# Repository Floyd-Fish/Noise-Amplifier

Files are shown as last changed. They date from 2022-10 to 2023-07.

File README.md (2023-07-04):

# Noise Amplifier

An ultra-low noise amplifier **(named EmoeNAP)** capable to measure low-noise LDO/OPA's wide band output noise, and many other interesting measurements. Referred to **[AN-159](https://www.analog.com/en/app-notes/an-159.html)**.

The full article about the initial version of Noise Amp can be found here:**[How to build a Noise Amplifier](https://www.emoe.xyz/noise-amplifier-building-instruction/)**. And to step further, to build the current version named **EmoeNAP**，please follow **[Noise Amplifier Step further](https://www.emoe.xyz/noise-amplifier-step-further/)**

Test result show that: with input shorted, the total output noise in 100kHz bandwidth is 1.76mVrms, and **the EmoeNAP's Gain equals to 80dB**, which results in **176nVrms input noise.**

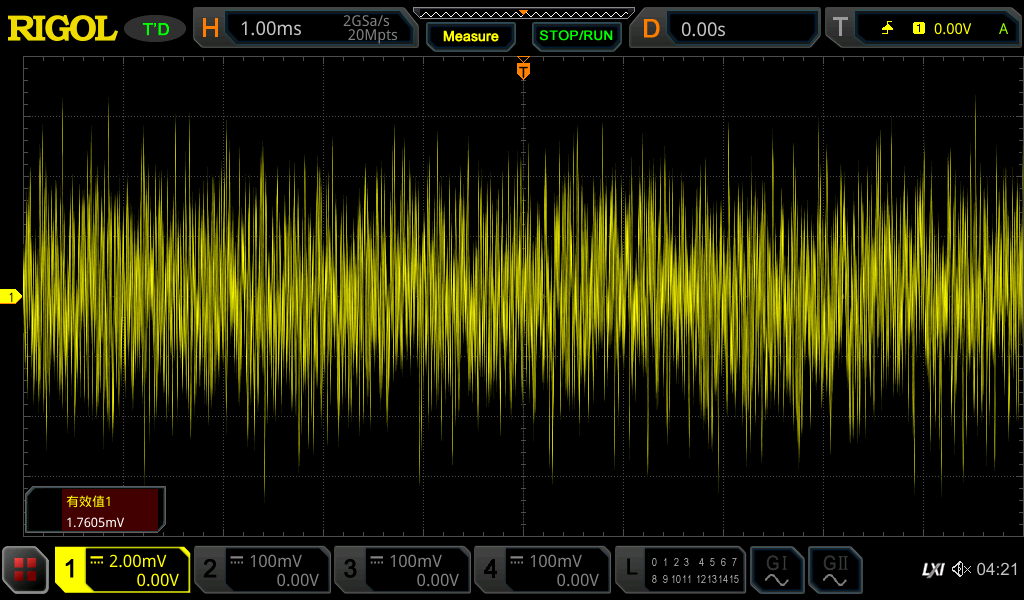
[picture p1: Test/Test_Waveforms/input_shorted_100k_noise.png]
input_shorted_noise


Then connect a 50 ohms SMA Load to input, the total output noise in 100kHz bandwidth is 3.65mVrms, which equals in 365nVrms input noise.

A 50 ohms resistor's Johnson-Nyquist Noise(Themal noise) in 100kHz is 316nVrms(Theoretical), and 316nVrms combine with 176nVrms, resulting 361nVrms total output noise. This test verified the EmoeNAP's extraordinary ability to measure a 50 ohms resistor's Thermal Noise precisely.

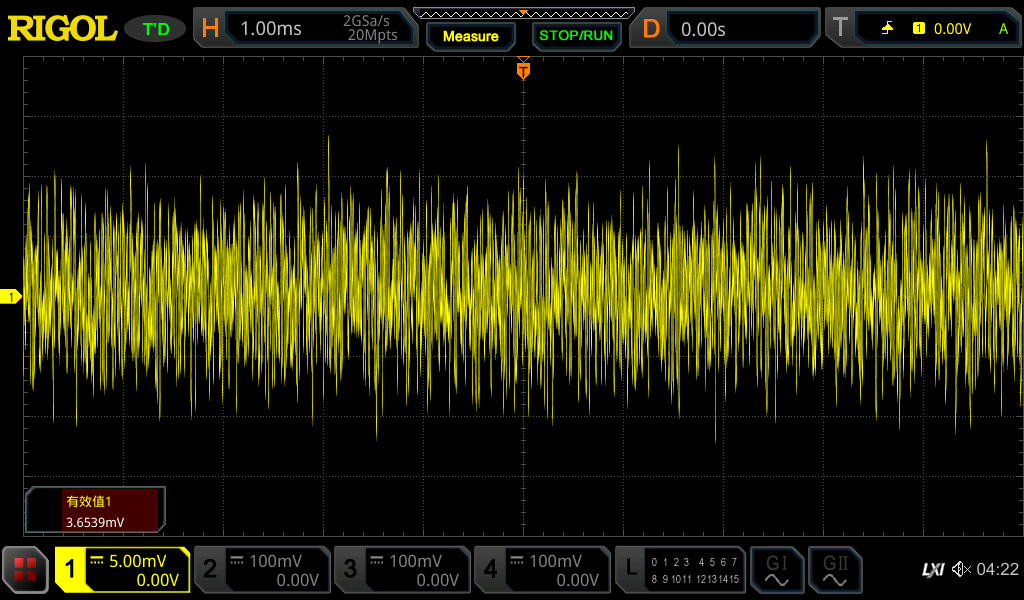
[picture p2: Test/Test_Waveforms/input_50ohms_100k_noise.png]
input_50ohms_noise


# Still In Progress

**V2.3 has been verified but still needs improving.**    
In next version of EmoeNAP, I plan to change its architecture a little to the form below:

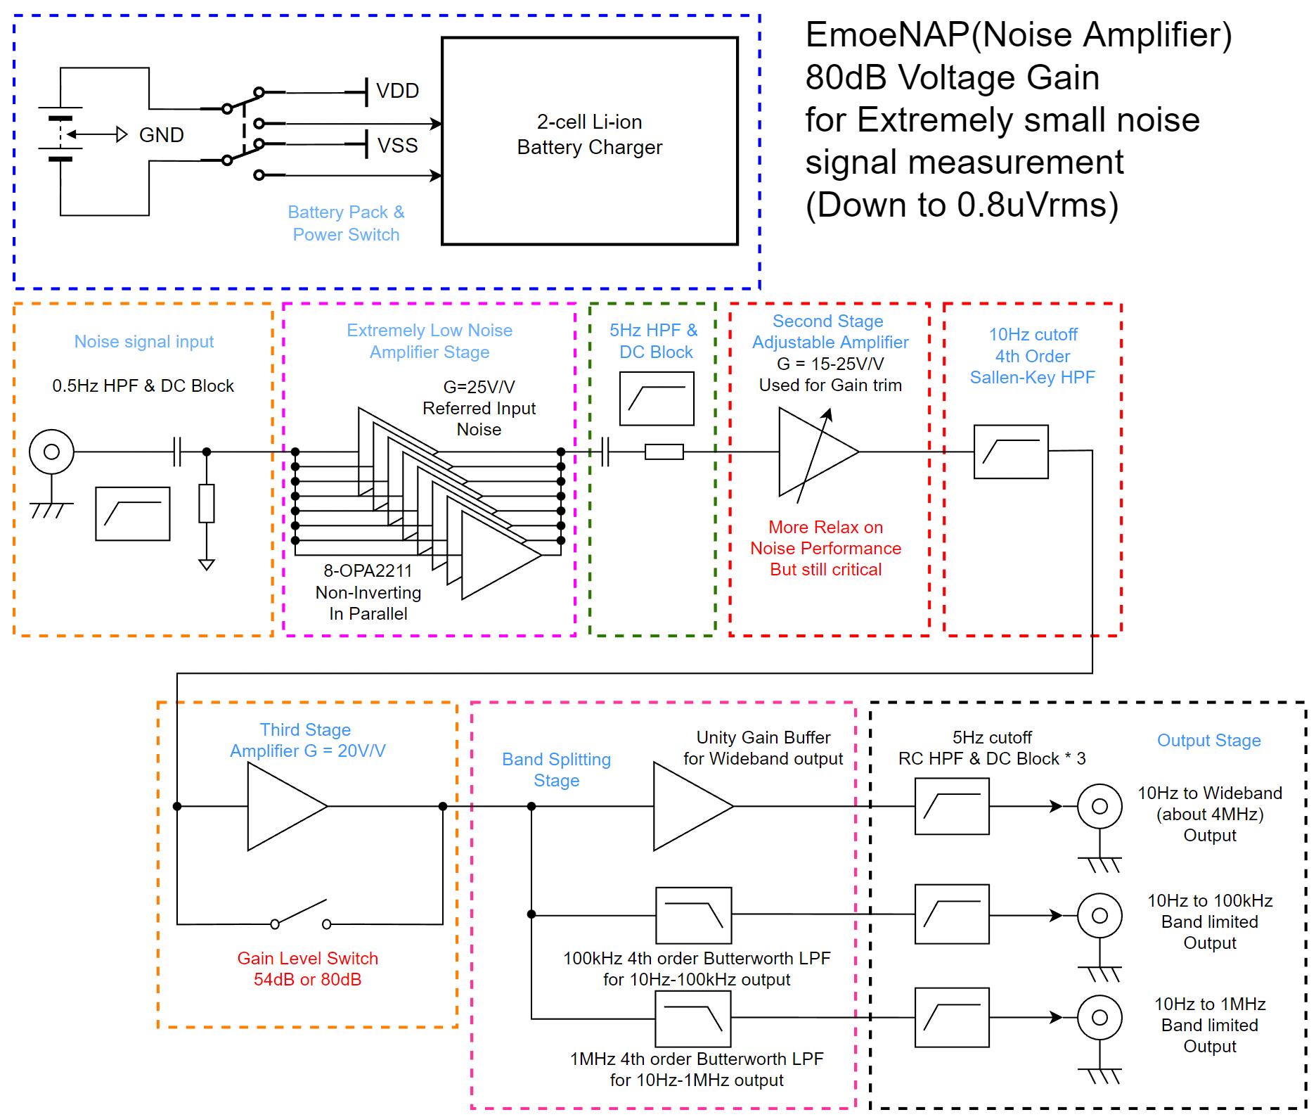
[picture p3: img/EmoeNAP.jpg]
EmoeNAP_Arch


## V2.3 Known Issue

- Poor layout of output low-pass filter, to be re-designed.  
- Input Riso is not needed, because it introduces more thermal noise to input.(Can be seen as source impedance)  
- A resistor should be connected in series at wideband output port, because capacitive load( osilloscope input port, such as) can cause loop instability problem, so a resistor is needed to isolate the opamp output to load capacitor. A common value of 100 ohms is recommended.

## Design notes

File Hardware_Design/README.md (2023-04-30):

# Hardware Specs

- NoiseAMP_BAT
> The battery pack for Noise Amplifier. Two 14500 Type 3.7V Li-ion Battery are used to provide ultralow power rail noise and high output current for NoiseAMP to work.

- NoiseAMP_V2.3(**Aborted**)
> The main PCB of the initial version of NoiseAMP, the current revision named EmoeNAP.

- EmoeNAP
> The current main PCB of NoiseAMP, called EmoeNAP, too.

To build a single cell EmoeNAP，**just use EmoeNAP is enough**.  
To build a 2-cell EmoeNAP, maybe you could have a look at NoiseAMP_BAT.

> Using one cell is more convenient to charge the battery, but will degrade noise performance a little bit.  
> Using two cell would get the best noise performance of EmoeNAP.

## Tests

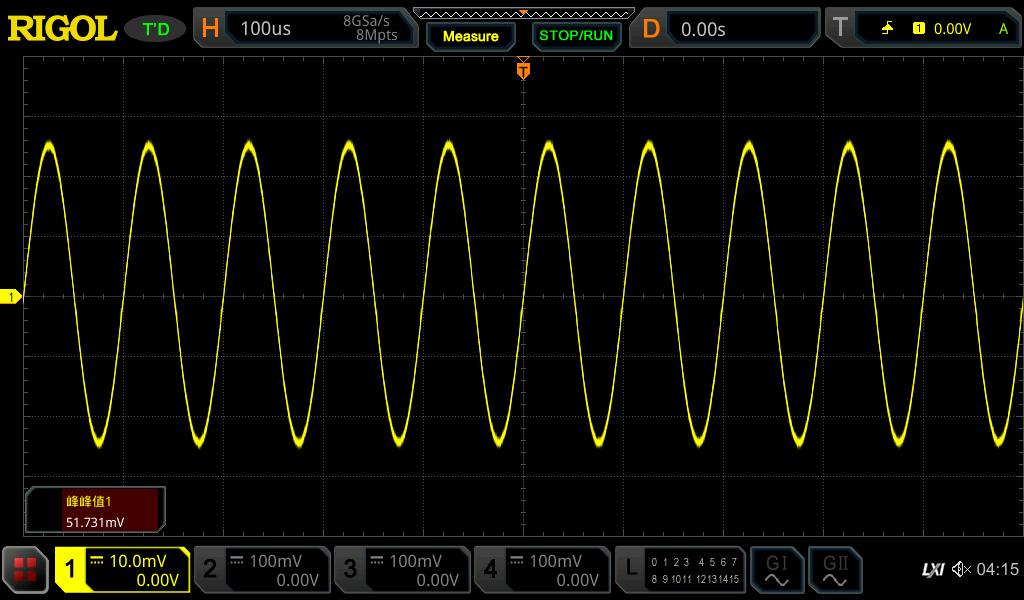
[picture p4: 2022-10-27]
Test/Test_Waveforms/40dB ATT 50mVpp Calibration.png

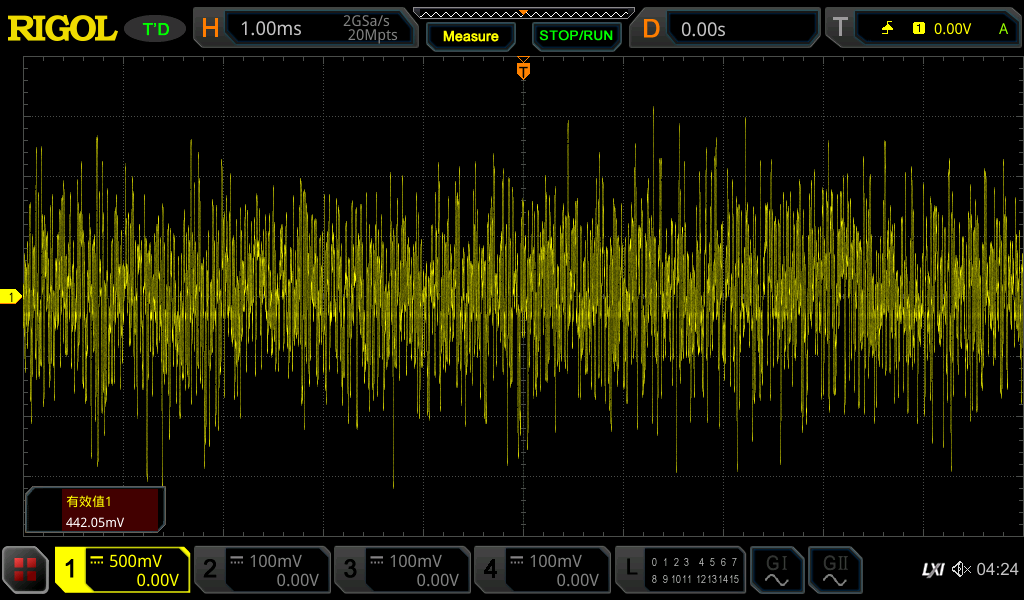
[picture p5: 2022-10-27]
Test/Test_Waveforms/LM399_output_100k_noise.png

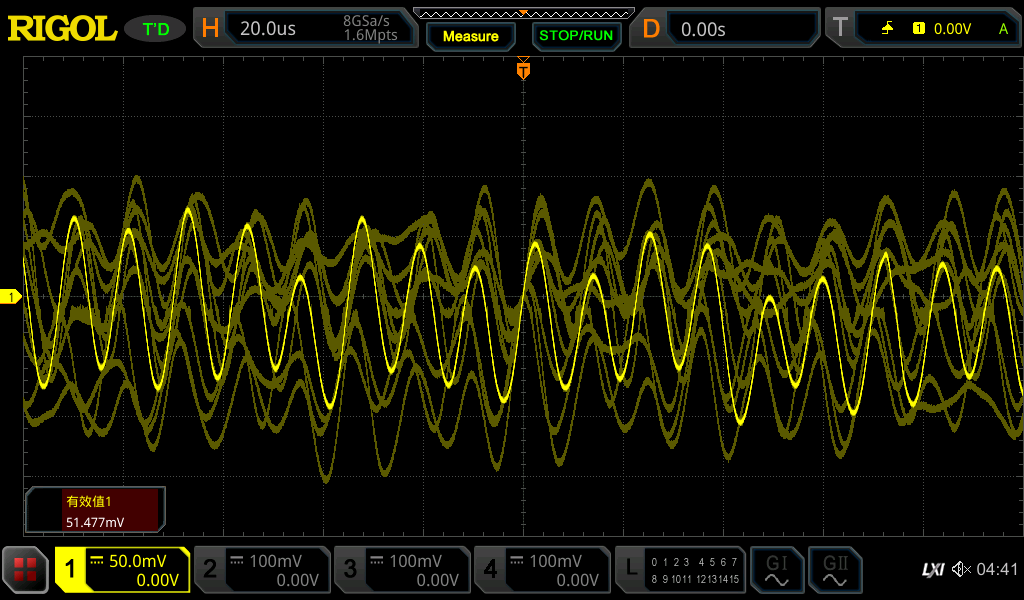
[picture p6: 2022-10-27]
Test/Test_Waveforms/lt3045_100k_noise_zoom.png

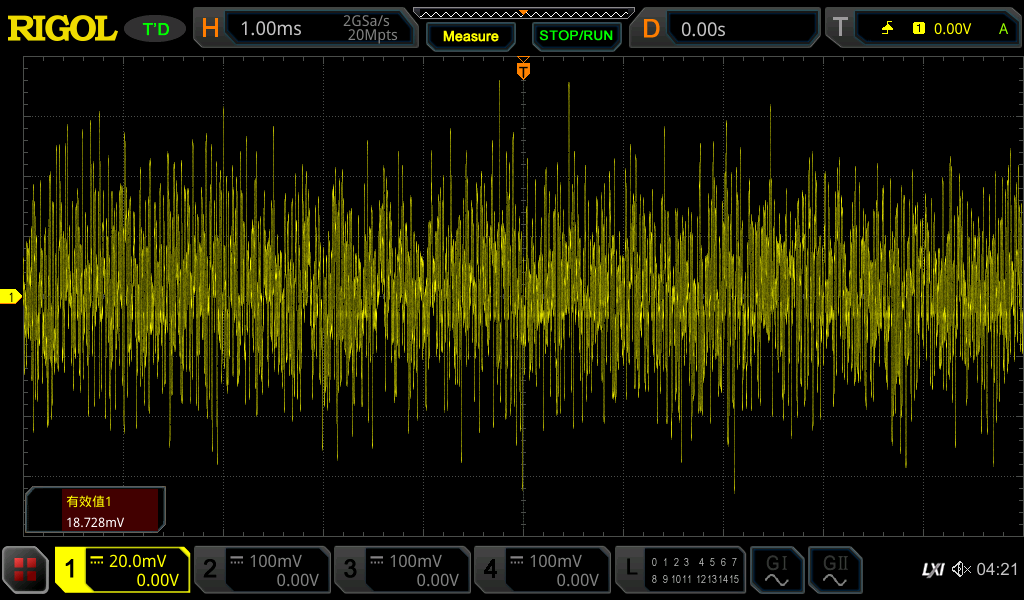
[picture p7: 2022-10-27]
Test/Test_Waveforms/input_floating_100k_noise.png

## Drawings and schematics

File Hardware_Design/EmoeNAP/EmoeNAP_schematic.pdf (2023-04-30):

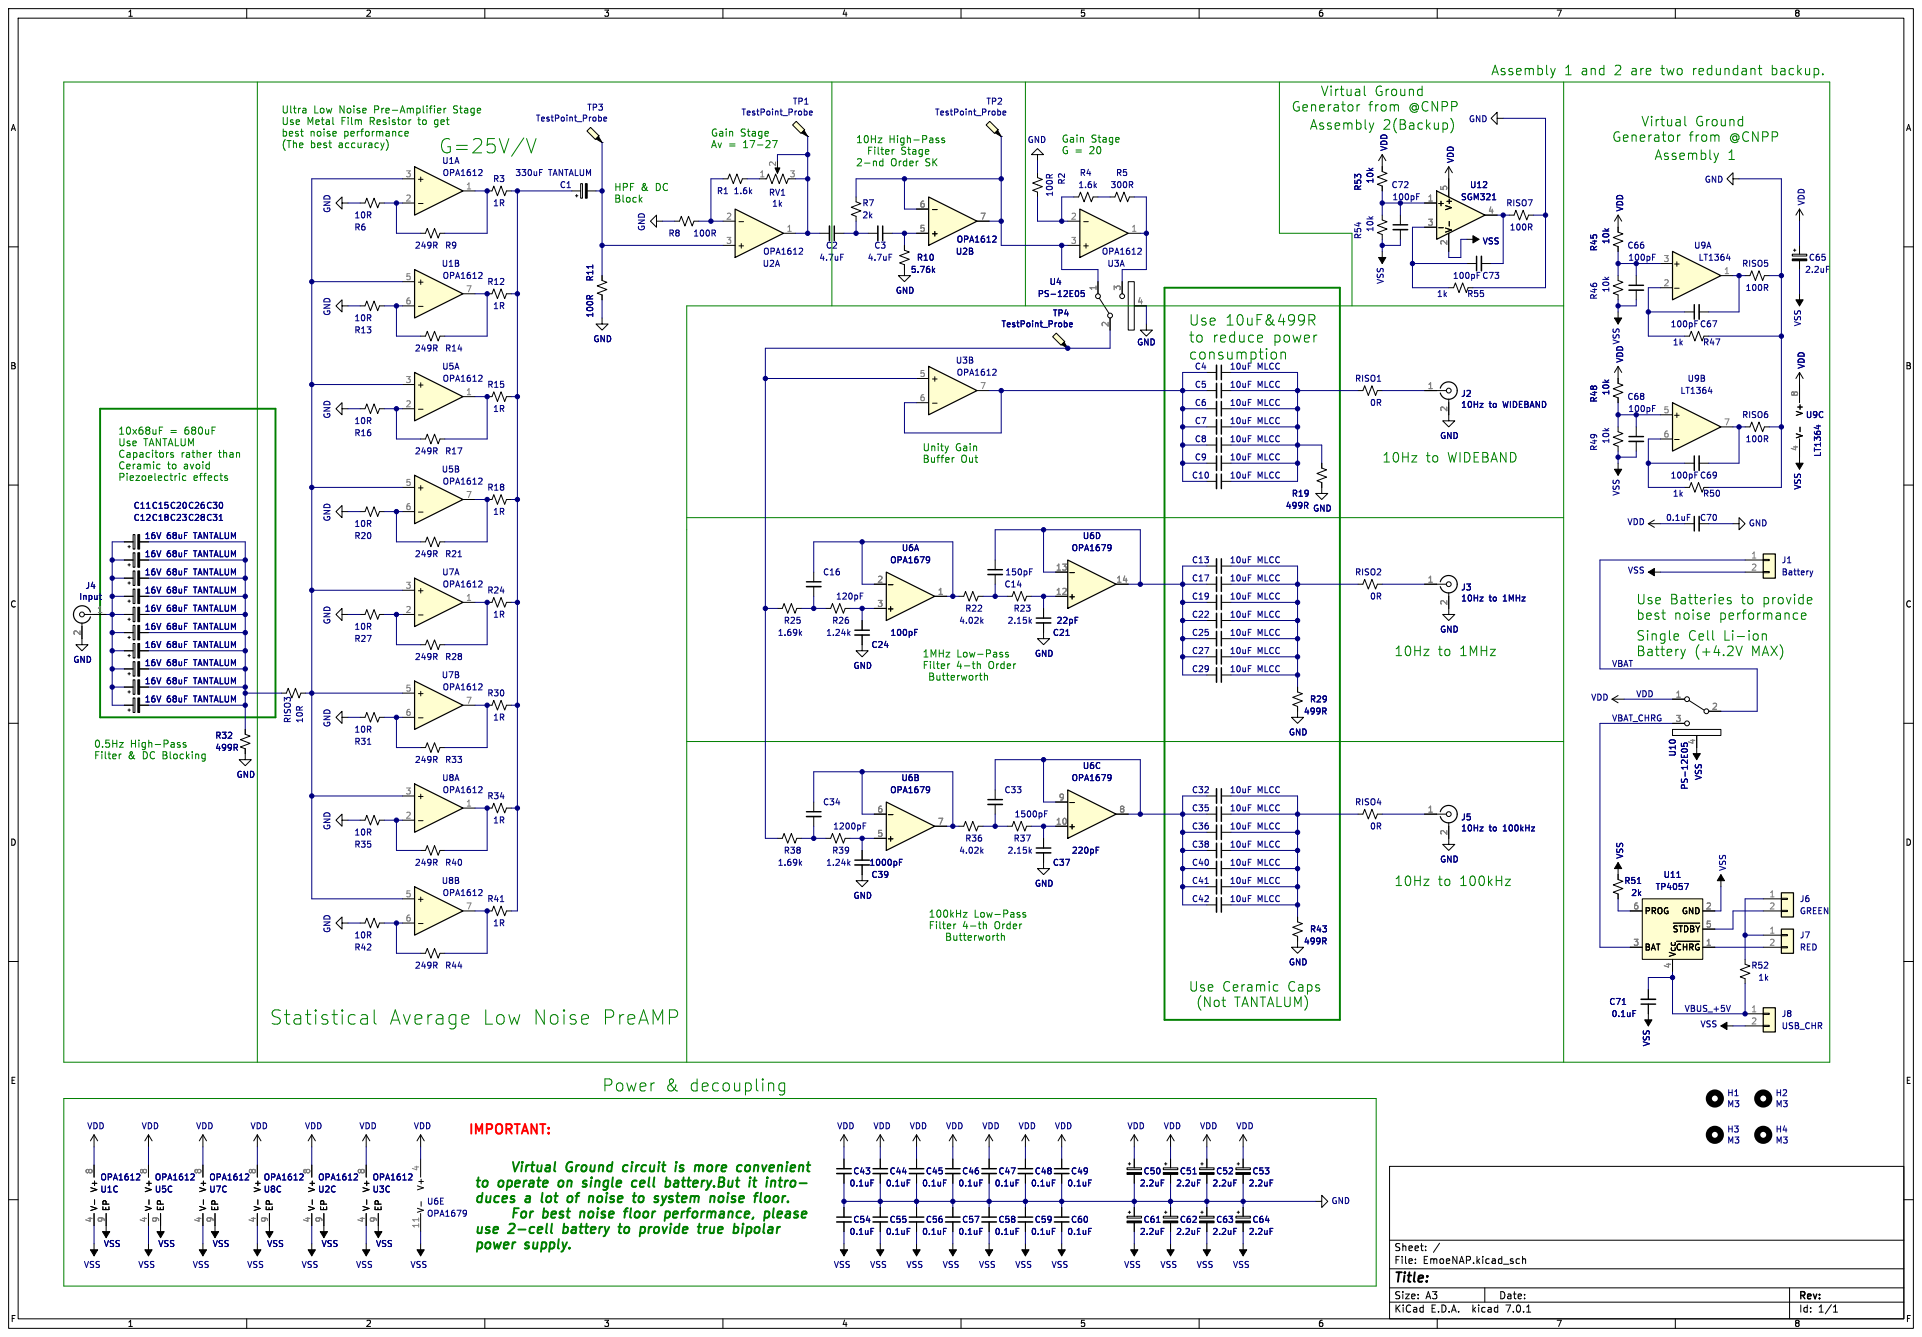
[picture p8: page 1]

Battery (+4.2V MAX) 10x68uF = 680uF Use TANTALUM

best noise performance
Single Cell Li-ion

0.5Hz High-Pass Filter & DC Blocking

9 VSS VSS VSS VSS U8C OPA1612 V- 4 V+

to operate on single cell battery.But it intro-
duces a lot of noise to system noise floor.

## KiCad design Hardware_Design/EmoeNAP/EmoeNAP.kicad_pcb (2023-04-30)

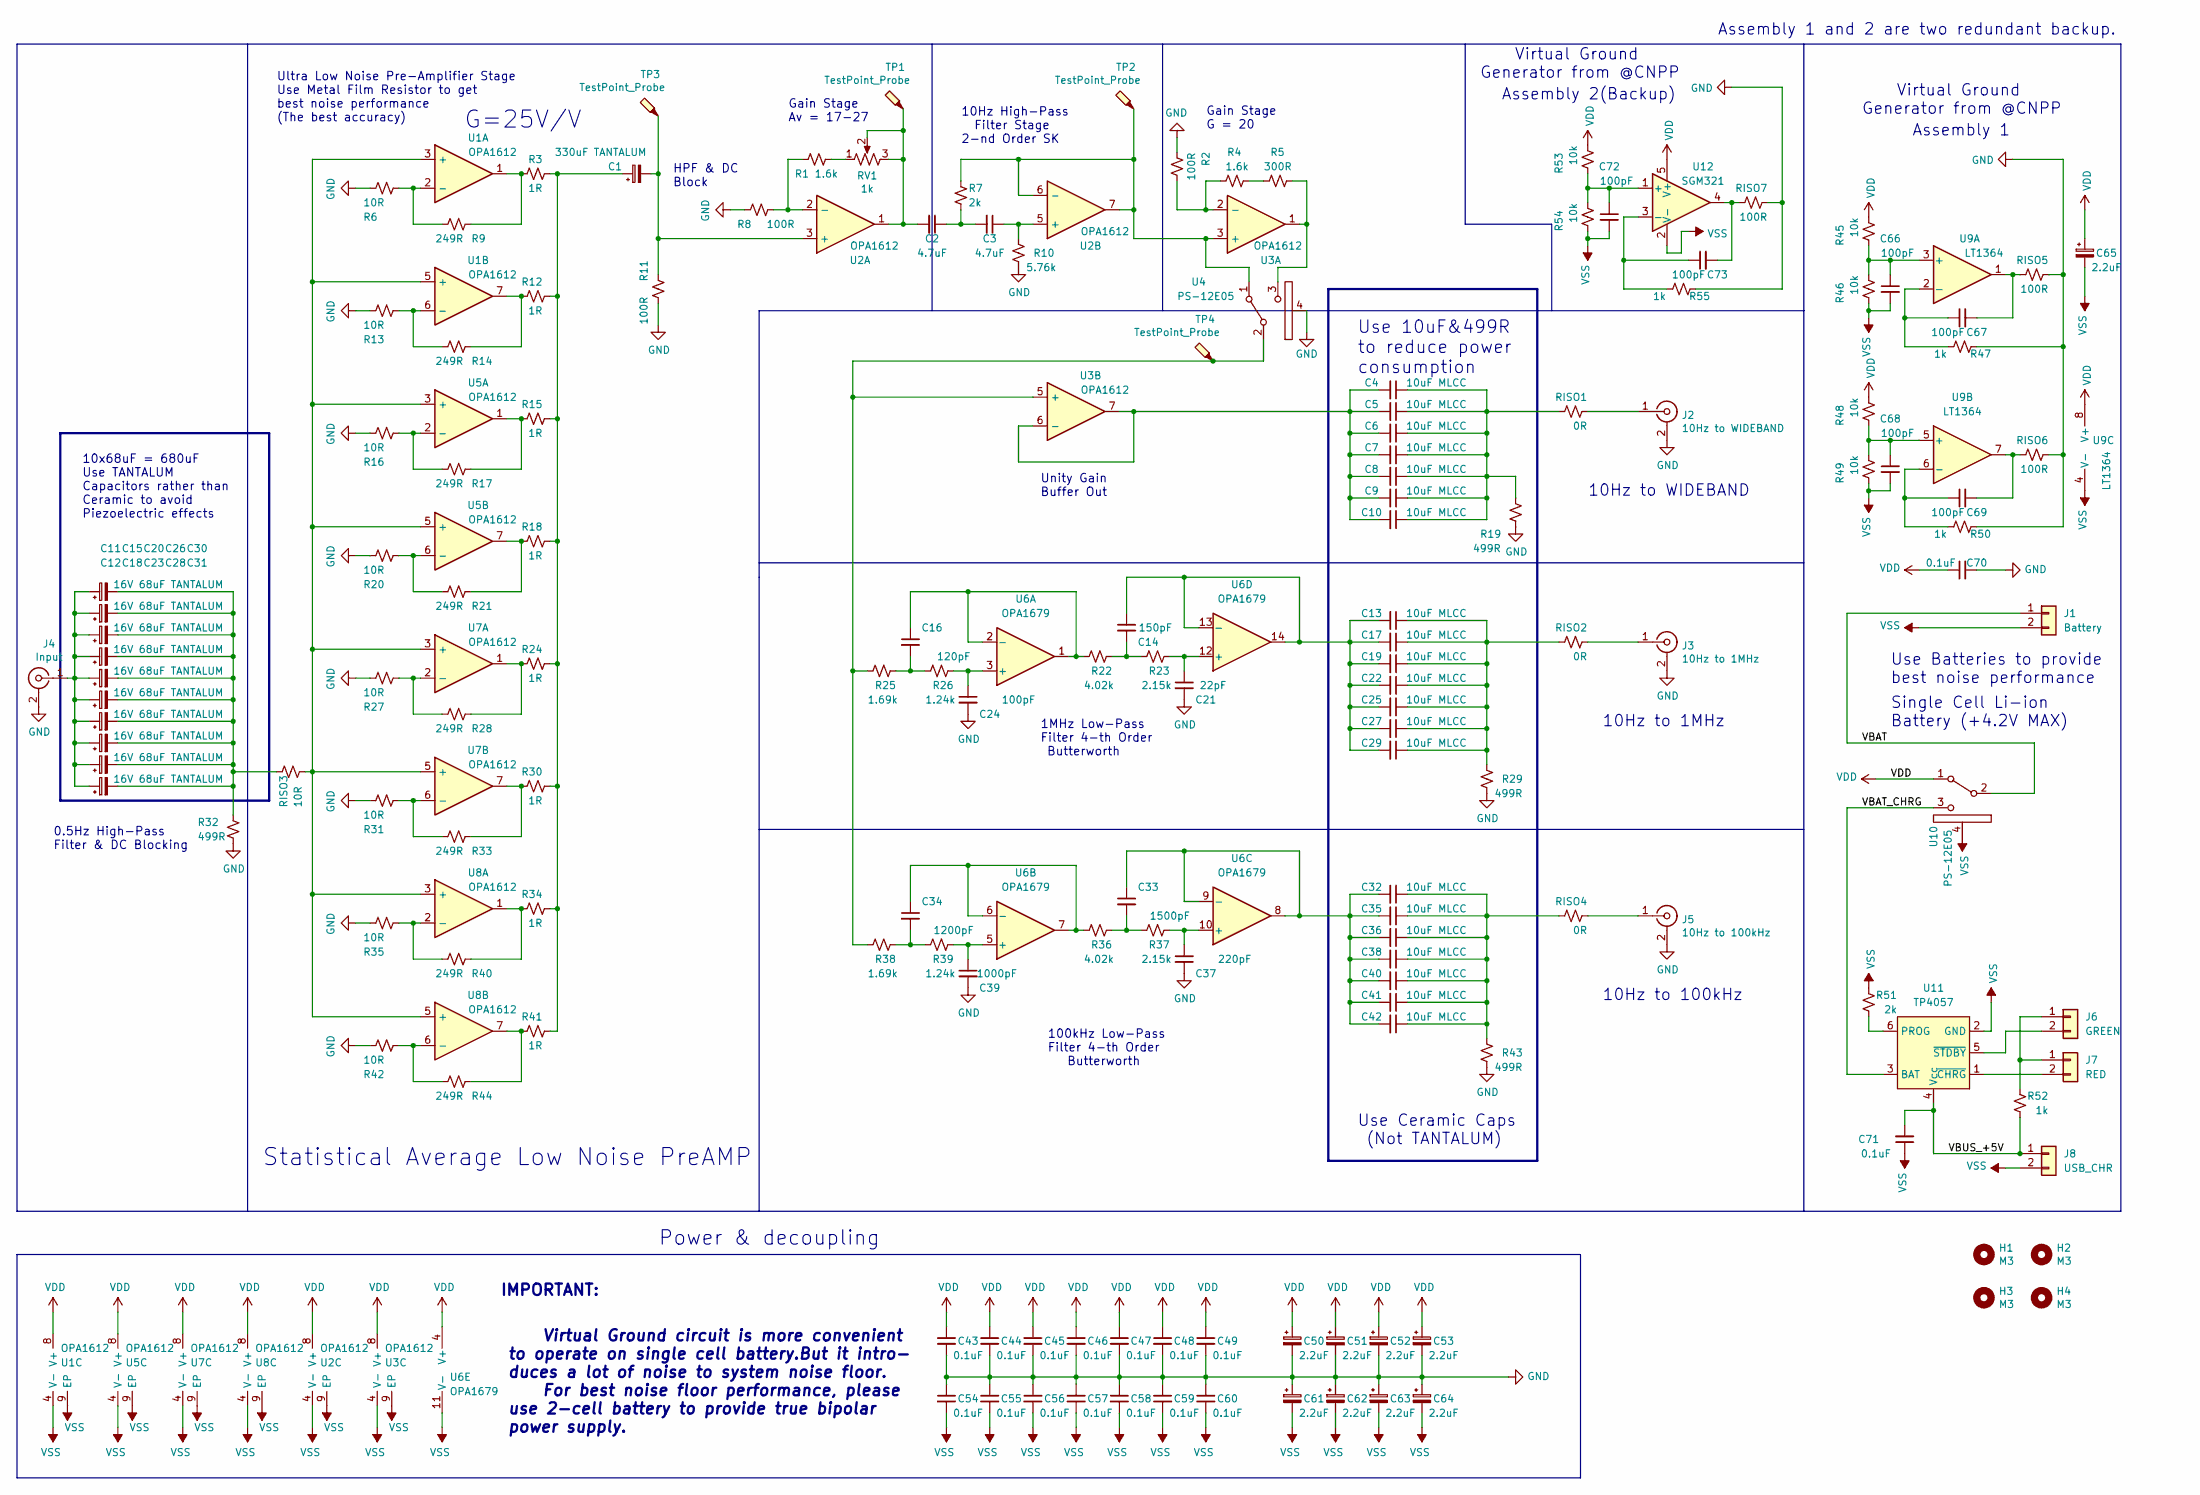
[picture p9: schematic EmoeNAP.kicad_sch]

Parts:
C1: 330uF TANTALUM; CP_EIA-6032-20_AVX-F
C2, C3: 4.7uF; C_0805_2012Metric
C4, C5, C6, C7, C8, C9, C10, C13, C17, C19, C22, C25, C27, C29, C32, C35, C36, C38, C40, C41, C42: 10uF MLCC; C_0805_2012Metric
C11, C12, C15, C18, C20, C23, C26, C28, C30, C31: 16V 68uF TANTALUM; CP_EIA-6032-20_AVX-F
C14: 150pF; C_0402_1005Metric
C16: 120pF; C_0402_1005Metric
C21: 22pF; C_0402_1005Metric
C24, C66, C67, C68, C69, C72, C73: 100pF; C_0402_1005Metric
C33: 1500pF; C_0402_1005Metric
C34: 1200pF; C_0402_1005Metric
C37: 220pF; C_0402_1005Metric
C39: 1000pF; C_0402_1005Metric
C43, C44, C45, C46, C47, C48, C49, C54, C55, C56, C57, C58, C59, C60, C70, C71: 0.1uF; C_0402_1005Metric
C50, C51, C52, C53, C61, C62, C63, C64, C65: 2.2uF; CP_EIA-3216-10_Kemet-I
H1, H2, H3, H4: M3; MountingHole_3.2mm_M3_Pad_TopOnly
J1: Battery; JST_XA_B02B-XASK-1_1x02_P2.50mm_Vertical
J2: 10Hz to WIDEBAND; U.FL_Molex_MCRF_73412-0110_Vertical
J3: 10Hz to 1MHz; U.FL_Molex_MCRF_73412-0110_Vertical
J4: Input; U.FL_Molex_MCRF_73412-0110_Vertical
J5: 10Hz to 100kHz; U.FL_Molex_MCRF_73412-0110_Vertical
J6: GREEN; TestPoint_2Pads_Pitch2.54mm_Drill0.8mm
J7: RED; TestPoint_2Pads_Pitch2.54mm_Drill0.8mm
J8: USB_CHR; JST_XA_B02B-XASK-1_1x02_P2.50mm_Vertical
R1, R4: 1.6k; R_0402_1005Metric
R2, R8, R11: 100R; R_0402_1005Metric
R3, R12, R15, R18, R24, R30, R34, R41: 1R; R_0402_1005Metric
R5: 300R; R_0402_1005Metric
R6, R13, R16, R20, R27, R31, R35, R42: 10R; R_0402_1005Metric
R7, R51: 2k; R_0402_1005Metric
R9, R14, R17, R21, R28, R33, R40, R44: 249R; R_0402_1005Metric
R10: 5.76k; R_0402_1005Metric
R19, R29, R32, R43: 499R; R_0805_2012Metric
R22, R36: 4.02k; R_0402_1005Metric
R23, R37: 2.15k; R_0402_1005Metric
R25, R38: 1.69k; R_0402_1005Metric
R26, R39: 1.24k; R_0402_1005Metric
R45, R46, R48, R49, R53, R54: 10k; R_0402_1005Metric
R47, R50, R52, R55: 1k; R_0402_1005Metric
RISO1, RISO2, RISO4: 0R; R_0805_2012Metric
RISO3: 10R; R_0805_2012Metric
RISO5, RISO6, RISO7: 100R; R_0603_1608Metric
RV1: 1k; Potentiometer_Bourns_3266W_Vertical
TP1, TP2, TP3, TP4: TestPoint_Probe; TestPoint_Pad_D1.0mm
U1, U2, U3, U5, U7, U8: OPA1612; WSON-8-1EP_3x3mm_P0.5mm_EP1.2x2mm
U4, U10: PS-12E05
U6: OPA1679; SOIC-14_3.9x8.7mm_P1.27mm
U9: LT1364; SOIC-8_3.9x4.9mm_P1.27mm
U11: TP4057; SOT-23-6
U12: SGM321; SOT-23-5

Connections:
/VBAT: J1.1, U10.2
/VBAT_CHRG: U10.3, U11.3 (BAT)
/VBUS_+5V: C71.2, J8.1, R52.1, U11.4 (Vcc)
GND: C21.2, C24.2, C37.2, C39.2, C43.2, C44.2, C45.2, C46.2, C47.2, C48.2, C49.2, C50.2, C51.2, C52.2, C53.2, C54.1, C55.1, C56.1, C57.1, C58.1, C59.1, C60.1, C61.1, C62.1, C63.1, C64.1, C70.2, J2.2 (Ext), J3.2 (Ext), J4.2 (Ext), J5.2 (Ext), R2.1, R6.2, R8.1, R10.2, R11.2, R13.2, R16.2, R19.2, R20.2, R27.2, R29.2, R31.2, R32.2, R35.2, R42.2, R43.2, R47.1, R50.1, R55.1, RISO5.2, RISO6.2, RISO7.2, U4.4
unnamed: C1.1, R3.2, R12.2, R15.2, R18.2, R24.2, R30.2, R34.2, R41.2
unnamed: C1.2, R11.1, TP3.1, U2.3 (+)
unnamed: C2.1, C3.2, R7.2
unnamed: C2.2, RV1.2, RV1.3, TP1.1, U2.1
unnamed: C3.1, R10.1, U2.5 (+)
unnamed: C4.1, C5.1, C6.1, C7.1, C8.1, C9.1, C10.1, R19.1, RISO1.1
unnamed: C4.2, C5.2, C6.2, C7.2, C8.2, C9.2, C10.2, U3.6 (-), U3.7
unnamed: C11.1, C12.1, C15.1, C18.1, C20.1, C23.1, C26.1, C28.1, C30.1, C31.1, J4.1 (In)
unnamed: C11.2, C12.2, C15.2, C18.2, C20.2, C23.2, C26.2, C28.2, C30.2, C31.2, R32.1, RISO3.1
unnamed: C13.1, C17.1, C19.1, C22.1, C25.1, C27.1, C29.1, R29.1, RISO2.1
unnamed: C13.2, C14.1, C17.2, C19.2, C22.2, C25.2, C27.2, C29.2, U6.13 (-), U6.14
unnamed: C14.2, R22.1, R23.2
unnamed: C16.1, R22.2, U6.1, U6.2 (-)
unnamed: C16.2, R25.1, R26.2
unnamed: C21.1, R23.1, U6.12 (+)
unnamed: C24.1, R26.1, U6.3 (+)
unnamed: C32.1, C35.1, C36.1, C38.1, C40.1, C41.1, C42.1, R43.1, RISO4.1
unnamed: C32.2, C33.1, C35.2, C36.2, C38.2, C40.2, C41.2, C42.2, U6.8, U6.9 (-)
unnamed: C33.2, R36.1, R37.2
unnamed: C34.1, R36.2, U6.6 (-), U6.7
unnamed: C34.2, R38.1, R39.2
unnamed: C37.1, R37.1, U6.10 (+)
unnamed: C39.1, R39.1, U6.5 (+)
unnamed: C66.1, R45.1, R46.2, U9.3 (+)
unnamed: C67.1, R47.2, U9.2 (-)
unnamed: C67.2, RISO5.1, U9.1
unnamed: C68.1, R48.1, R49.2, U9.5 (+)
unnamed: C69.1, R50.2, U9.6 (-)
unnamed: C69.2, RISO6.1, U9.7
unnamed: C72.1, R53.1, R54.2, U12.1 (+)
unnamed: C73.1, R55.2, U12.3 (-)
unnamed: C73.2, RISO7.1, U12.4
unnamed: J2.1 (In), RISO1.2
unnamed: J3.1 (In), RISO2.2
unnamed: J5.1 (In), RISO4.2
unnamed: J6.1, J7.1, R52.2
unnamed: J6.2, U11.5 (~STDBY)
unnamed: J7.2, U11.1 (~CHRG)
unnamed: R1.1, R8.2, U2.2 (-)
unnamed: R1.2, RV1.1
unnamed: R2.2, R4.1, U3.2 (-)
unnamed: R3.1, R9.1, U1.1
unnamed: R4.2, R5.1
unnamed: R5.2, U3.1, U4.3
unnamed: R6.1, R9.2, U1.2 (-)
unnamed: R7.1, TP2.1, U2.6 (-), U2.7, U3.3 (+), U4.1
unnamed: R12.1, R14.1, U1.7
unnamed: R13.1, R14.2, U1.6 (-)
unnamed: R15.1, R17.1, U5.1
unnamed: R16.1, R17.2, U5.2 (-)
unnamed: R18.1, R21.1, U5.7
unnamed: R20.1, R21.2, U5.6 (-)
unnamed: R24.1, R28.1, U7.1
unnamed: R25.2, R38.2, TP4.1, U3.5 (+), U4.2
unnamed: R27.1, R28.2, U7.2 (-)
unnamed: R30.1, R33.1, U7.7
unnamed: R31.1, R33.2, U7.6 (-)
unnamed: R34.1, R40.1, U8.1
unnamed: R35.1, R40.2, U8.2 (-)
unnamed: R41.1, R44.1, U8.7
unnamed: R42.1, R44.2, U8.6 (-)
unnamed: R51.1, U11.6 (PROG)
unnamed: RISO3.2, U1.3 (+), U1.5 (+), U5.3 (+), U5.5 (+), U7.3 (+), U7.5 (+), U8.3 (+), U8.5 (+)
VDD: C43.1, C44.1, C45.1, C46.1, C47.1, C48.1, C49.1, C50.1, C51.1, C52.1, C53.1, C65.1, C70.1, R45.2, R48.2, R53.2, U1.8 (V+), U2.8 (V+), U3.8 (V+), U5.8 (V+), U6.4 (V+), U7.8 (V+), U8.8 (V+), U9.8 (V+), U10.1, U12.5 (V+)
VSS: C54.2, C55.2, C56.2, C57.2, C58.2, C59.2, C60.2, C61.2, C62.2, C63.2, C64.2, C65.2, C66.2, C68.2, C71.1, C72.2, J1.2, J8.2, R46.1, R49.1, R51.2, R54.1, U1.4 (V-), U1.9 (EP), U2.4 (V-), U2.9 (EP), U3.4 (V-), U3.9 (EP), U5.4 (V-), U5.9 (EP), U6.11 (V-), U7.4 (V-), U7.9 (EP), U8.4 (V-), U8.9 (EP), U9.4 (V-), U10.4, U11.2 (GND), U12.2 (V-)

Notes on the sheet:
100kHz Low-Pass Filter 4-th Order Butterworth
Use 10uF&499R to reduce power consumption
Single Cell Li-ion Battery (+4.2V MAX)
0.5Hz High-Pass Filter & DC Blocking
10x68uF = 680uF Use TANTALUM Capacitors rather than Ceramic to avoid Piezoelectric effects
Statistical Average Low Noise PreAMP
G=25V/V
1MHz Low-Pass Filter 4-th Order Butterworth
HPF & DC Block
Virtual Ground Generator from @CNPP
10Hz to 100kHz
Assembly 2(Backup)
Use Batteries to provide best noise performance
10Hz High-Pass Filter Stage 2-nd Order SK
Power & decoupling
Unity Gain Buffer Out
IMPORTANT:
Ultra Low Noise Pre-Amplifier Stage Use Metal Film Resistor to get best noise performance (The best accuracy)
10Hz to 1MHz
Virtual Ground circuit is more convenient to operate on single cell battery.But it intro- duces a lot of noise to system noise floor. For best noise floor performance, please use 2-cell battery to provide true bipolar power supply.
10Hz to WIDEBAND
Use Ceramic Caps (Not TANTALUM)
Assembly 1 and 2 are two redundant backup.
Gain Stage G = 20
Gain Stage Av = 17-27
Assembly 1

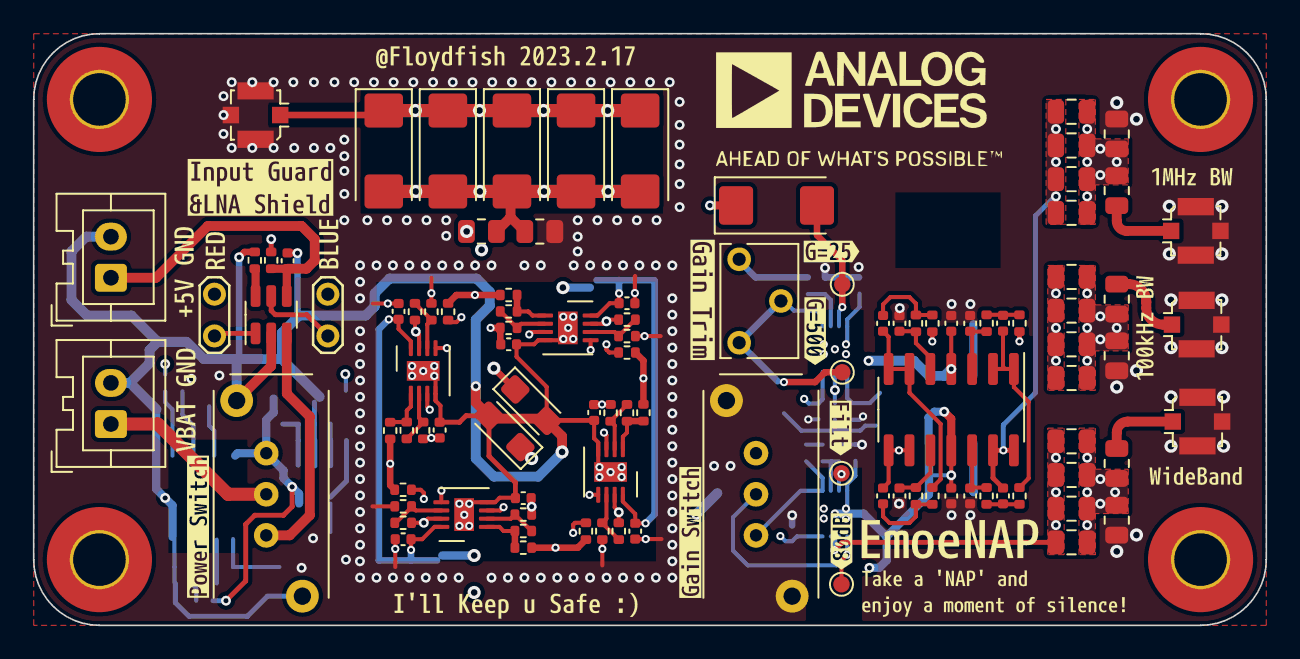
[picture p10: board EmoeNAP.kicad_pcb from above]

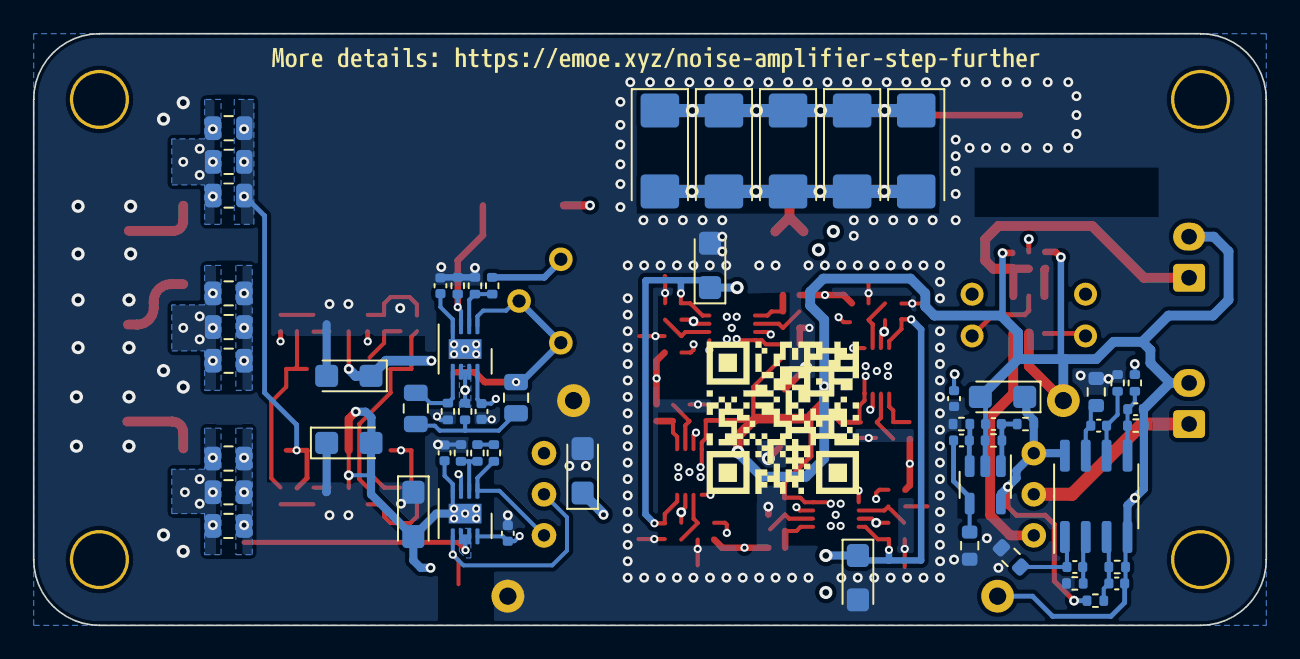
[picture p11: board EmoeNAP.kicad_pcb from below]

Board: 4 copper layers, 75.0 x 36.0 mm, 184 parts (59 on the bottom side), 69 nets.

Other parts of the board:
kibuzzard-63ED0A5F: G***; kibuzzard-63ED0A5F
kibuzzard-63EE51C1: G***; kibuzzard-63EE51C1
kibuzzard-63EE51DC: G***; kibuzzard-63EE51DC
kibuzzard-63EE53DB: G***; kibuzzard-63EE53DB
kibuzzard-63EE512D: G***; kibuzzard-63EE512D
kibuzzard-63EE520C: G***; kibuzzard-63EE520C
kibuzzard-63EE5216: G***; kibuzzard-63EE5216
kibuzzard-63EE5345: G***; kibuzzard-63EE5345
kibuzzard-6378A7DC: G***; kibuzzard-6378A7DC
kibuzzard-6378A7EA: G***; kibuzzard-6378A7EA
kibuzzard-6378A7F5: G***; kibuzzard-6378A7F5
kibuzzard-6378A8E8: G***; kibuzzard-6378A8E8
kibuzzard-6378A91A: G***; kibuzzard-6378A91A
kibuzzard-6378A94A: G***; kibuzzard-6378A94A
kibuzzard-6378A590: G***; kibuzzard-6378A590
kibuzzard-6378A691: G***; kibuzzard-6378A691
kibuzzard-6378A997: G***; kibuzzard-6378A997
kibuzzard-6378AA98: G***; kibuzzard-6378AA98
kibuzzard-6378AAC6: G***; kibuzzard-6378AAC6
kibuzzard-6378AB16: G***; kibuzzard-6378AB16

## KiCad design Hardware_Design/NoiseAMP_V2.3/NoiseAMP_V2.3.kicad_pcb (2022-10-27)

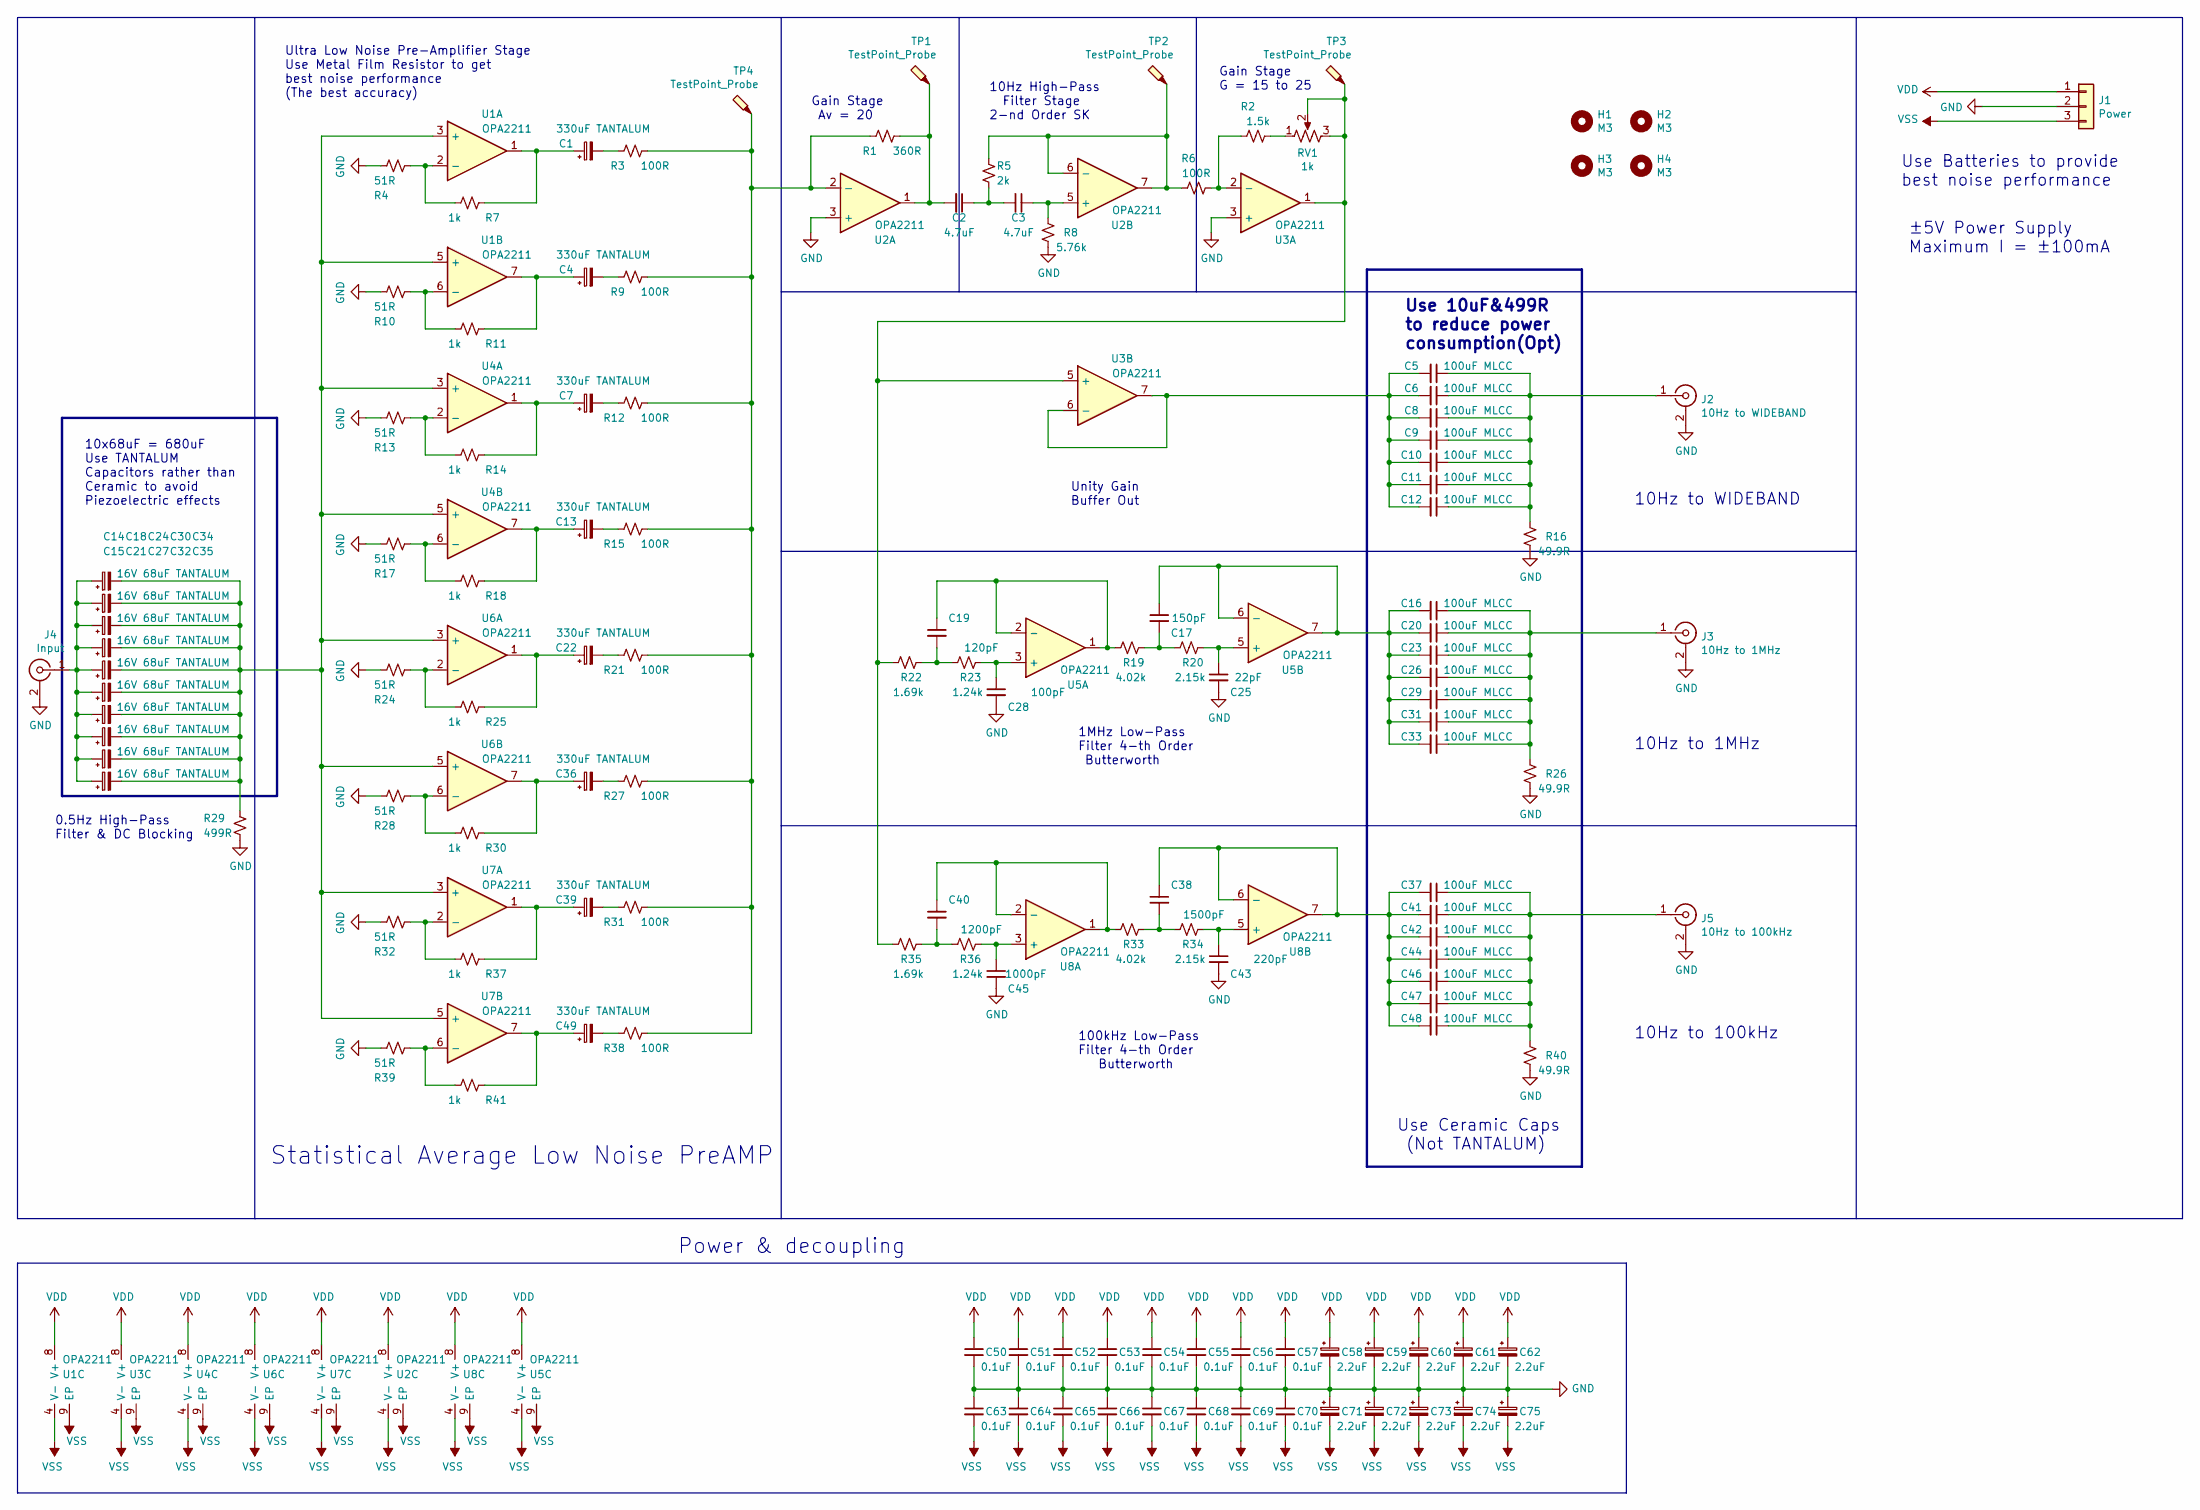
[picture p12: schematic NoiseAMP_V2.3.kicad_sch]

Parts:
C1, C4, C7, C13, C22, C36, C39, C49: 330uF TANTALUM; CP_EIA-6032-20_AVX-F
C2, C3: 4.7uF; C_0805_2012Metric
C5, C6, C8, C9, C10, C11, C12, C16, C20, C23, C26, C29, C31, C33, C37, C41, C42, C44, C46, C47, C48: 100uF MLCC; C_1206_3216Metric
C14, C15, C18, C21, C24, C27, C30, C32, C34, C35: 16V 68uF TANTALUM; CP_EIA-6032-20_AVX-F
C17: 150pF; C_0402_1005Metric
C19: 120pF; C_0402_1005Metric
C25: 22pF; C_0402_1005Metric
C28: 100pF; C_0402_1005Metric
C38: 1500pF; C_0402_1005Metric
C40: 1200pF; C_0402_1005Metric
C43: 220pF; C_0402_1005Metric
C45: 1000pF; C_0402_1005Metric
C50, C51, C52, C53, C54, C55, C56, C57, C63, C64, C65, C66, C67, C68, C69, C70: 0.1uF; C_0402_1005Metric
C58, C59, C60, C61, C62, C71, C72, C73, C74, C75: 2.2uF; CP_EIA-3216-10_Kemet-I
H1, H2, H3, H4: M3; MountingHole_3.2mm_M3_Pad_TopOnly
J1: Power; JST_XH_B3B-XH-A_1x03_P2.50mm_Vertical
J2: 10Hz to WIDEBAND; U.FL_Molex_MCRF_73412-0110_Vertical
J3: 10Hz to 1MHz; U.FL_Molex_MCRF_73412-0110_Vertical
J4: Input; U.FL_Molex_MCRF_73412-0110_Vertical
J5: 10Hz to 100kHz; U.FL_Molex_MCRF_73412-0110_Vertical
R1: 360R; R_0402_1005Metric
R2: 1.5k; R_0402_1005Metric
R3, R6, R9, R12, R15, R21, R27, R31, R38: 100R; R_0402_1005Metric
R4, R10, R13, R17, R24, R28, R32, R39: 51R; R_0402_1005Metric
R5: 2k; R_0402_1005Metric
R7, R11, R14, R18, R25, R30, R37, R41: 1k; R_0402_1005Metric
R8: 5.76k; R_0402_1005Metric
R16, R26, R40: 49.9R; R_0402_1005Metric
R19, R33: 4.02k; R_0402_1005Metric
R20, R34: 2.15k; R_0402_1005Metric
R22, R35: 1.69k; R_0402_1005Metric
R23, R36: 1.24k; R_0402_1005Metric
R29: 499R; R_0402_1005Metric
RV1: 1k; Potentiometer_Bourns_3296W_Vertical
TP1, TP2, TP3, TP4: TestPoint_Probe; TestPoint_Pad_D1.0mm
U1, U2, U3, U4, U5, U6, U7, U8: OPA2211; WSON-8-1EP_3x3mm_P0.5mm_EP1.2x2mm

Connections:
GND: C25.2, C28.2, C43.2, C45.2, C50.2, C51.2, C52.2, C53.2, C54.2, C55.2, C56.2, C57.2, C58.2, C59.2, C60.2, C61.2, C62.2, C63.1, C64.1, C65.1, C66.1, C67.1, C68.1, C69.1, C70.1, C71.1, C72.1, C73.1, C74.1, C75.1, J1.2, J2.2 (Ext), J3.2 (Ext), J4.2 (Ext), J5.2 (Ext), R4.2, R8.2, R10.2, R13.2, R16.2, R17.2, R24.2, R26.2, R28.2, R29.2, R32.2, R39.2, R40.2, U2.3 (+), U3.3 (+)
unnamed: C1.1, R7.1, U1.1
unnamed: C1.2, R3.1
unnamed: C2.1, C3.2, R5.2
unnamed: C2.2, R1.2, TP1.1, U2.1
unnamed: C3.1, R8.1, U2.5 (+)
unnamed: C4.1, R11.1, U1.7
unnamed: C4.2, R9.1
unnamed: C7.1, R14.1, U4.1
unnamed: C7.2, R12.1
unnamed: C5.1, C6.1, C8.1, C9.1, C10.1, C11.1, C12.1, J2.1 (In), R16.1
unnamed: C5.2, C6.2, C8.2, C9.2, C10.2, C11.2, C12.2, U3.6 (-), U3.7
unnamed: C13.1, R18.1, U4.7
unnamed: C13.2, R15.1
unnamed: C14.1, C15.1, C18.1, C21.1, C24.1, C27.1, C30.1, C32.1, C34.1, C35.1, J4.1 (In)
unnamed: C14.2, C15.2, C18.2, C21.2, C24.2, C27.2, C30.2, C32.2, C34.2, C35.2, R29.1, U1.3 (+), U1.5 (+), U4.3 (+), U4.5 (+), U6.3 (+), U6.5 (+), U7.3 (+), U7.5 (+)
unnamed: C16.1, C20.1, C23.1, C26.1, C29.1, C31.1, C33.1, J3.1 (In), R26.1
unnamed: C16.2, C17.1, C20.2, C23.2, C26.2, C29.2, C31.2, C33.2, U5.6 (-), U5.7
unnamed: C17.2, R19.1, R20.2
unnamed: C19.1, R19.2, U5.1, U5.2 (-)
unnamed: C19.2, R22.1, R23.2
unnamed: C22.1, R25.1, U6.1
unnamed: C22.2, R21.1
unnamed: C25.1, R20.1, U5.5 (+)
unnamed: C28.1, R23.1, U5.3 (+)
unnamed: C36.1, R30.1, U6.7
unnamed: C36.2, R27.1
unnamed: C37.1, C41.1, C42.1, C44.1, C46.1, C47.1, C48.1, J5.1 (In), R40.1
unnamed: C37.2, C38.1, C41.2, C42.2, C44.2, C46.2, C47.2, C48.2, U8.6 (-), U8.7
unnamed: C38.2, R33.1, R34.2
unnamed: C39.1, R37.1, U7.1
unnamed: C39.2, R31.1
unnamed: C40.1, R33.2, U8.1, U8.2 (-)
unnamed: C40.2, R35.1, R36.2
unnamed: C43.1, R34.1, U8.5 (+)
unnamed: C45.1, R36.1, U8.3 (+)
unnamed: C49.1, R41.1, U7.7
unnamed: C49.2, R38.1
unnamed: R1.1, R3.2, R9.2, R12.2, R15.2, R21.2, R27.2, R31.2, R38.2, TP4.1, U2.2 (-)
unnamed: R2.1, R6.2, U3.2 (-)
unnamed: R2.2, RV1.1
unnamed: R4.1, R7.2, U1.2 (-)
unnamed: R5.1, R6.1, TP2.1, U2.6 (-), U2.7
unnamed: R10.1, R11.2, U1.6 (-)
unnamed: R13.1, R14.2, U4.2 (-)
unnamed: R17.1, R18.2, U4.6 (-)
unnamed: R22.2, R35.2, RV1.2, RV1.3, TP3.1, U3.1, U3.5 (+)
unnamed: R24.1, R25.2, U6.2 (-)
unnamed: R28.1, R30.2, U6.6 (-)
unnamed: R32.1, R37.2, U7.2 (-)
unnamed: R39.1, R41.2, U7.6 (-)
VDD: C50.1, C51.1, C52.1, C53.1, C54.1, C55.1, C56.1, C57.1, C58.1, C59.1, C60.1, C61.1, C62.1, J1.1, U1.8 (V+), U2.8 (V+), U3.8 (V+), U4.8 (V+), U5.8 (V+), U6.8 (V+), U7.8 (V+), U8.8 (V+)
VSS: C63.2, C64.2, C65.2, C66.2, C67.2, C68.2, C69.2, C70.2, C71.2, C72.2, C73.2, C74.2, C75.2, J1.3, U1.4 (V-), U1.9 (EP), U2.4 (V-), U2.9 (EP), U3.4 (V-), U3.9 (EP), U4.4 (V-), U4.9 (EP), U5.4 (V-), U5.9 (EP), U6.4 (V-), U6.9 (EP), U7.4 (V-), U7.9 (EP), U8.4 (V-), U8.9 (EP)

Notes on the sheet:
100kHz Low-Pass Filter 4-th Order Butterworth
Use 10uF&499R to reduce power consumption(Opt)
0.5Hz High-Pass Filter & DC Blocking
10x68uF = 680uF Use TANTALUM Capacitors rather than Ceramic to avoid Piezoelectric effects
Statistical Average Low Noise PreAMP
1MHz Low-Pass Filter 4-th Order Butterworth
10Hz to 100kHz
10Hz High-Pass Filter Stage 2-nd Order SK
Power & decoupling
Unity Gain Buffer Out
Use Batteries to provide best noise performance
Ultra Low Noise Pre-Amplifier Stage Use Metal Film Resistor to get best noise performance (The best accuracy)
10Hz to 1MHz
±5V Power Supply Maximum I = ±100mA
10Hz to WIDEBAND
Use Ceramic Caps (Not TANTALUM)
Gain Stage G = 15 to 25
Gain Stage Av = 20

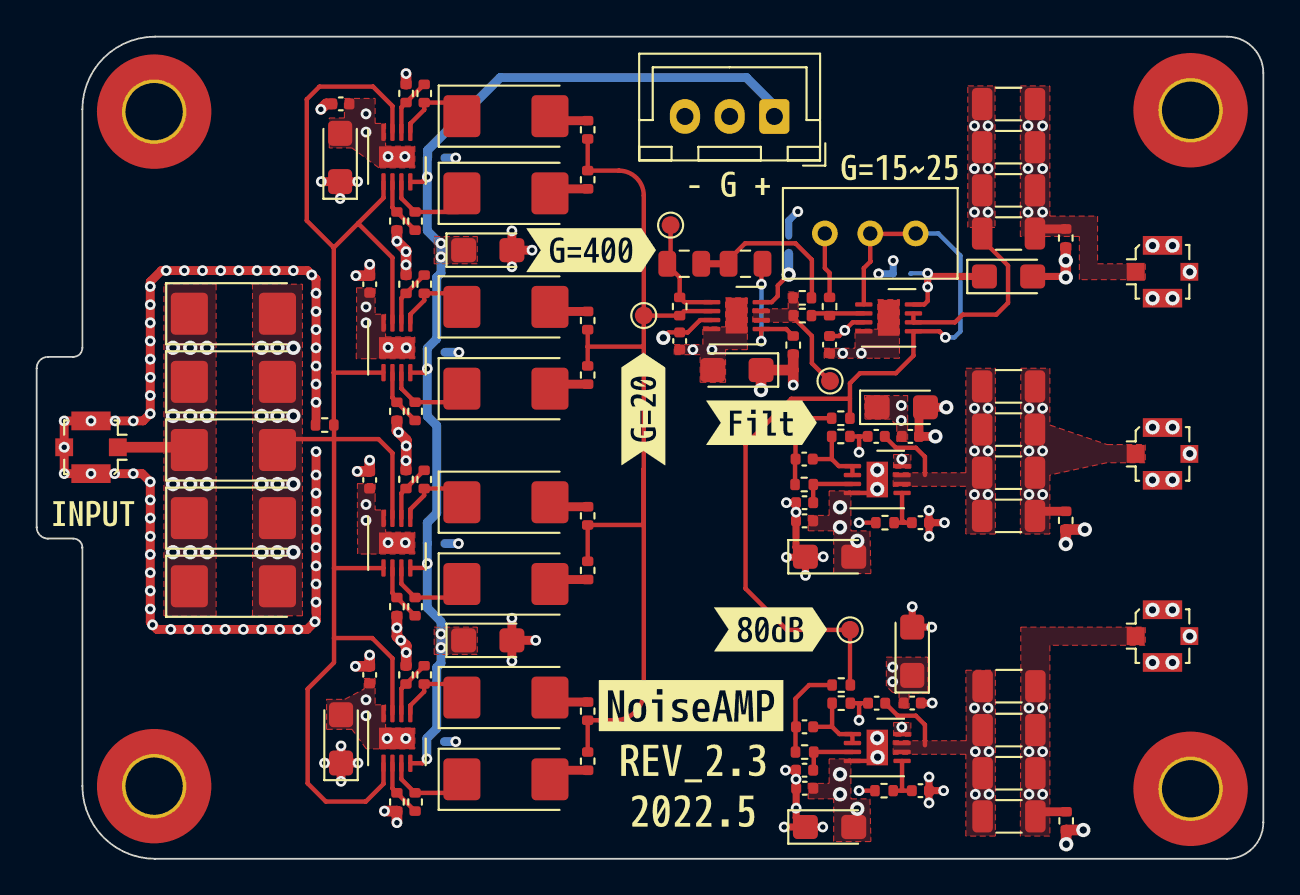
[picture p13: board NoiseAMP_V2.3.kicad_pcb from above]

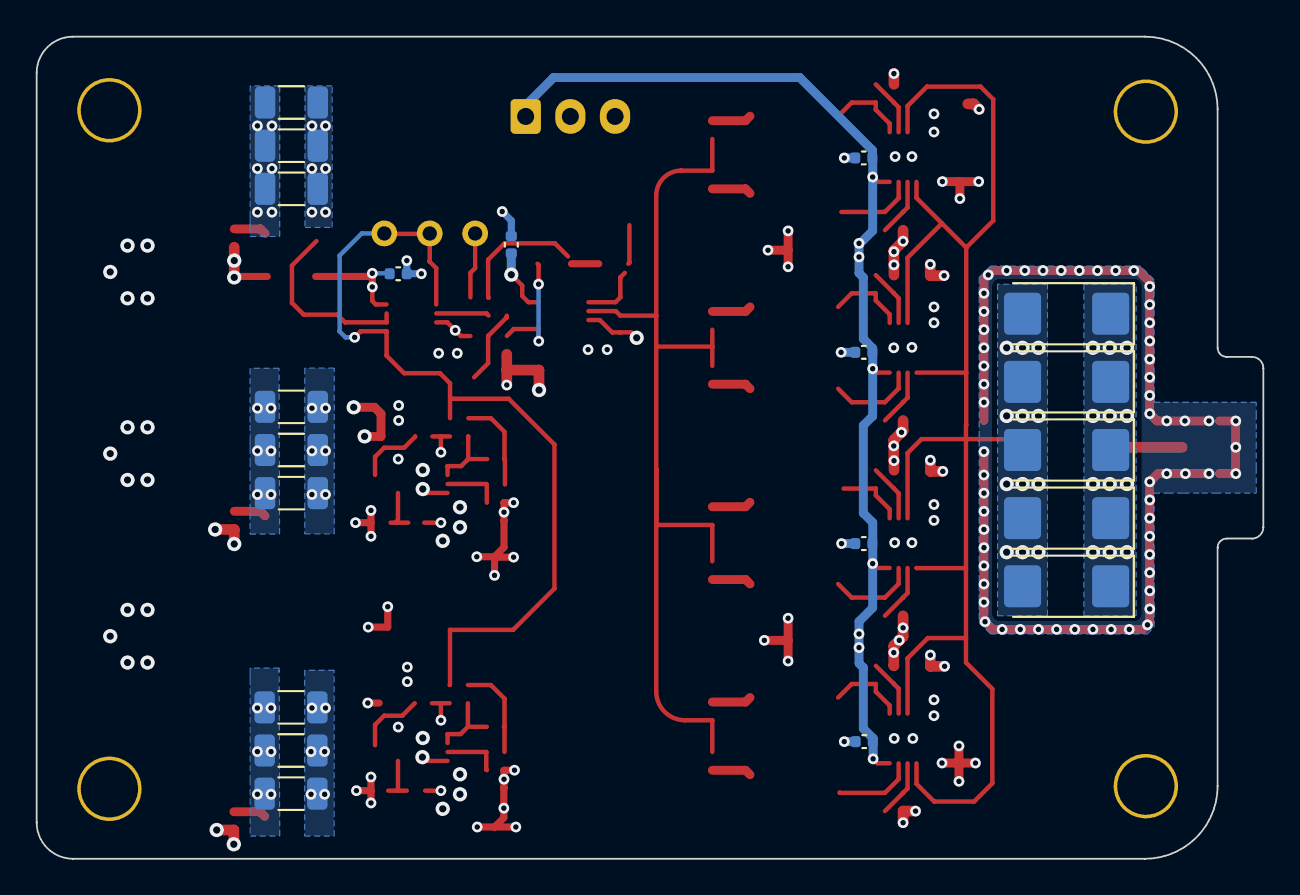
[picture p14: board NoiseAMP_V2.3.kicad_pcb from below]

Board: 4 copper layers, 68.6 x 46.0 mm, 148 parts (20 on the bottom side), 53 nets.

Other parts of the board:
kibuzzard-62753A7A: G***; kibuzzard-62753A7A
kibuzzard-62753A96: G***; kibuzzard-62753A96
kibuzzard-6238052E: G***; kibuzzard-6238052E
kibuzzard-6238054F: G***; kibuzzard-6238054F
kibuzzard-6238081A: G***; kibuzzard-6238081A
kibuzzard-6275398E: G***; kibuzzard-6275398E
kibuzzard-62380362: G***; kibuzzard-62380362
kibuzzard-62380566: G***; kibuzzard-62380566
kibuzzard-62380599: G***; kibuzzard-62380599
kibuzzard-62380883: G***; kibuzzard-62380883

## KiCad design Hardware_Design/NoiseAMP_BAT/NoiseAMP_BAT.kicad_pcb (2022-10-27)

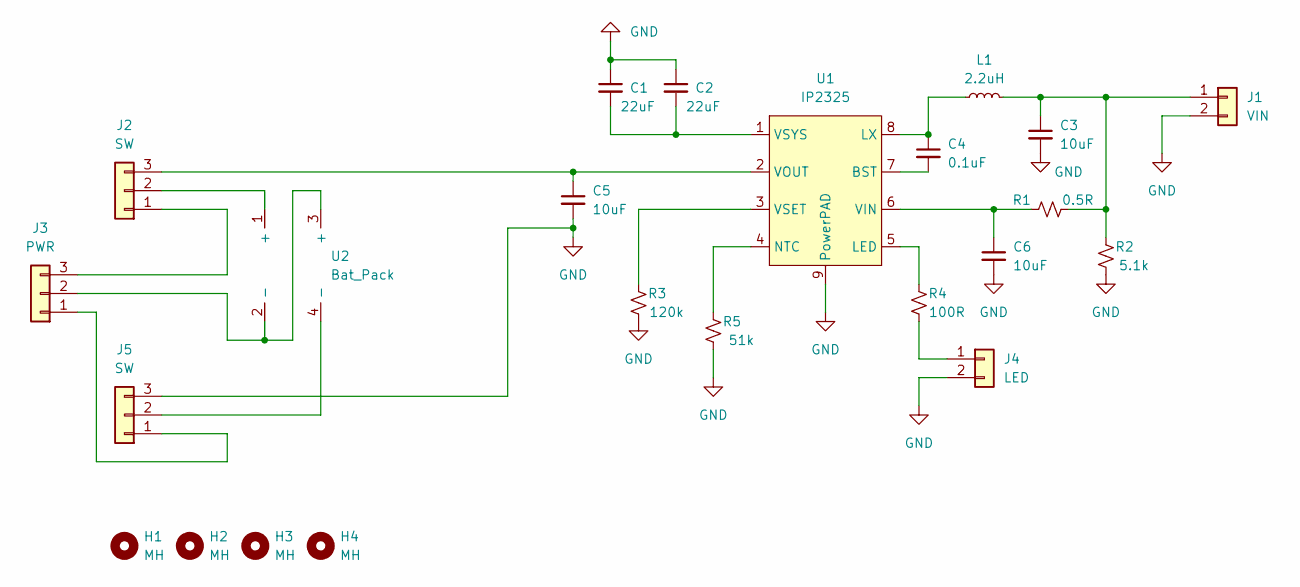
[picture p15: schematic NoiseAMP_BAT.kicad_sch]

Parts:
C1, C2: 22uF; C_1206_3216Metric
C3, C5, C6: 10uF; C_1206_3216Metric
C4: 0.1uF; C_0805_2012Metric
H1, H2, H3, H4: MH; MountingHole_3.2mm_M3_ISO7380
J1: VIN; JST_XA_B02B-XASK-1_1x02_P2.50mm_Vertical
J2, J5: SW; JST_XA_B03B-XASK-1_1x03_P2.50mm_Vertical
J3: PWR; JST_XA_B03B-XASK-1_1x03_P2.50mm_Vertical
J4: LED; JST_XA_B02B-XASK-1_1x02_P2.50mm_Vertical
L1: 2.2uH; L_Sumida_CDMC6D28_7.25x6.5mm
R1: 0.5R; R_0805_2012Metric
R2: 5.1k; R_0805_2012Metric
R3: 120k; R_0805_2012Metric
R4: 100R; R_0805_2012Metric
R5: 51k; R_0805_2012Metric
U1: IP2325; SOIC-8-1EP_3.9x4.9mm_P1.27mm_EP2.29x3mm
U2: Bat_Pack; 2AA_CELL

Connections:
GND: C1.1, C2.1, C3.2, C5.2, C6.2, J1.2, J4.2, J5.3, R2.1, R3.1, R5.1, U1.9 (PowerPAD)
unnamed: C1.2, C2.2, U1.1 (VSYS)
unnamed: C4.1, L1.1, U1.8 (LX)
unnamed: C4.2, U1.7 (BST)
unnamed: C5.1, J2.3, U1.2 (VOUT)
unnamed: C6.1, R1.1, U1.6 (VIN)
unnamed: J2.1, J3.3
unnamed: J2.2, U2.1 (+)
unnamed: J3.1, J5.1
unnamed: J3.2, U2.2 (-), U2.3 (+)
unnamed: J4.1, R4.1
unnamed: J5.2, U2.4 (-)
unnamed: C3.1, J1.1, L1.2, R1.2, R2.2
unnamed: R3.2, U1.3 (VSET)
unnamed: R4.2, U1.5 (LED)
unnamed: R5.2, U1.4 (NTC)

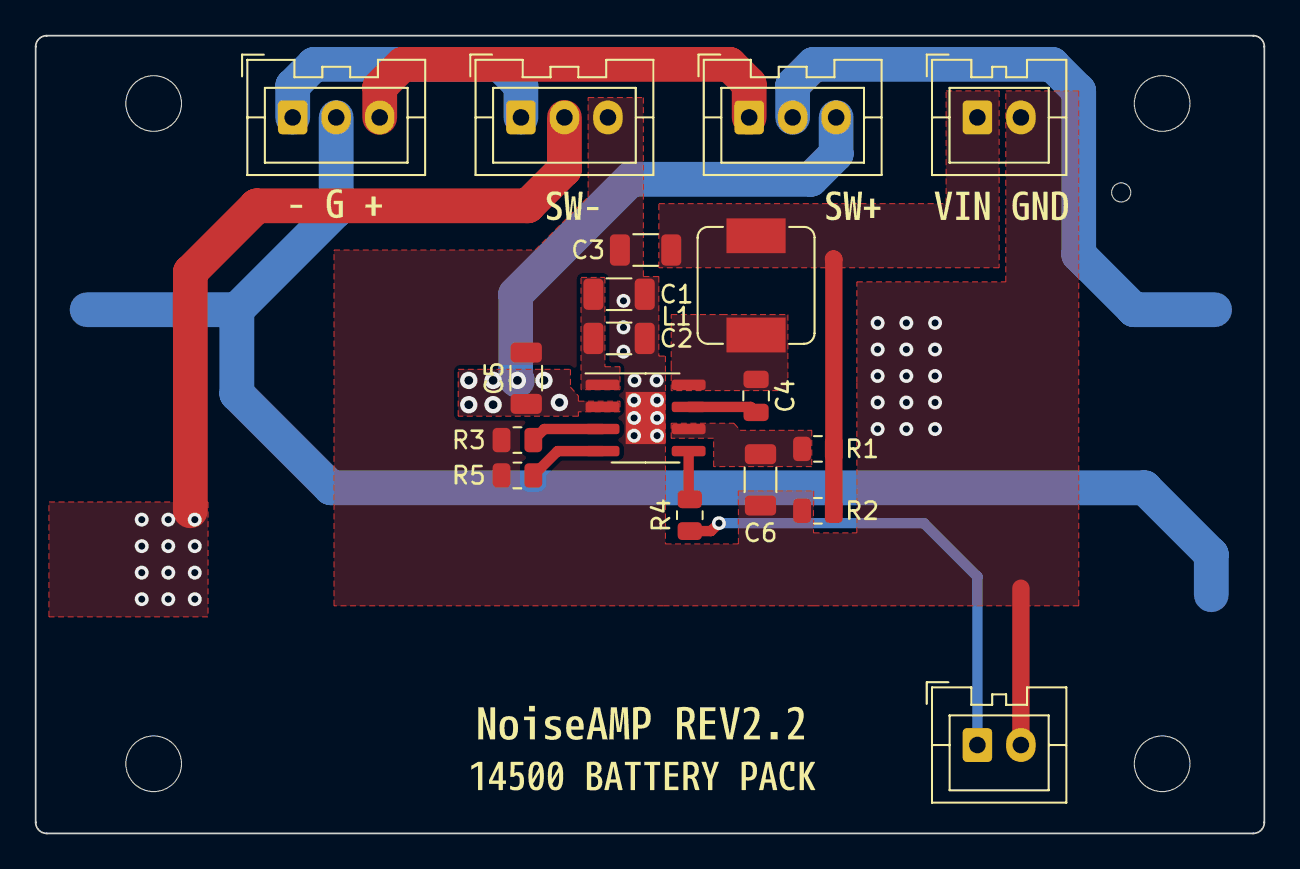
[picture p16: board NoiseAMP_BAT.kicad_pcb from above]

Board: 2 copper layers, 70.6 x 45.8 mm, 29 parts (1 on the bottom side), 16 nets.

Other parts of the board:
kibuzzard-624F939D: G***; kibuzzard-624F939D
kibuzzard-624F940E: G***; kibuzzard-624F940E
kibuzzard-624F9385: G***; kibuzzard-624F9385
kibuzzard-624F9417: G***; kibuzzard-624F9417
kibuzzard-624F9427: G***; kibuzzard-624F9427
kibuzzard-624F9438: G***; kibuzzard-624F9438

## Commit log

2022-10-27 Add V2.3 Design files and update EmoeNAP dev plans
    [NoiseAMP_BAT-B_Cu.gbr, NoiseAMP_BAT-B_Mask.gbr, NoiseAMP_BAT-B_Paste.gbr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]
2022-11-19 Update EmoeNAP PCB files
    [EmoeNAP-B_Cu.gbr, EmoeNAP-B_Mask.gbr, EmoeNAP-B_Paste.gbr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]
2023-04-30 Update EmoeNAP design
    [EmoeNAP-B_Cu.gbr, EmoeNAP-B_Mask.gbr, EmoeNAP-B_Paste.gbr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]
2023-07-04 Update progress and notes
    [EmoeNAP.kicad_sch]
